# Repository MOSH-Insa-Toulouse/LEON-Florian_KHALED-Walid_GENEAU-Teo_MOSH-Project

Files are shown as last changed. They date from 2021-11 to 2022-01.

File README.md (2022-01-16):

___

# Keywords

___
> Arduino, Kicad, The Thing Networks, Lora, Node-Red, LT-spice  

___
# Membres du groupe

> Ce projet à été réalisé par : 
> - GENEAU Téo
> - KHALED Walid
> - LEON Florian
> 
___
# Description générale du projet 

Nous voulons dans ce projet réaliser un smart device, nous voulons récupérer les données d’un capteur de gaz et les envoyer via le protocole LORA sur le site TTN et ensuite afficher les données du capteur sur un Dashboard sur Node-Red. Nous nous intéressons aussi à la consommation d’Energie du capteur, donc nous allons utiliser le capteur sous un mode réveillé (très bref moment) pour mesurer et envoyer les données et un autre mode endormi où il ne consomme quasiment rien (pendant la majorité du temps).     

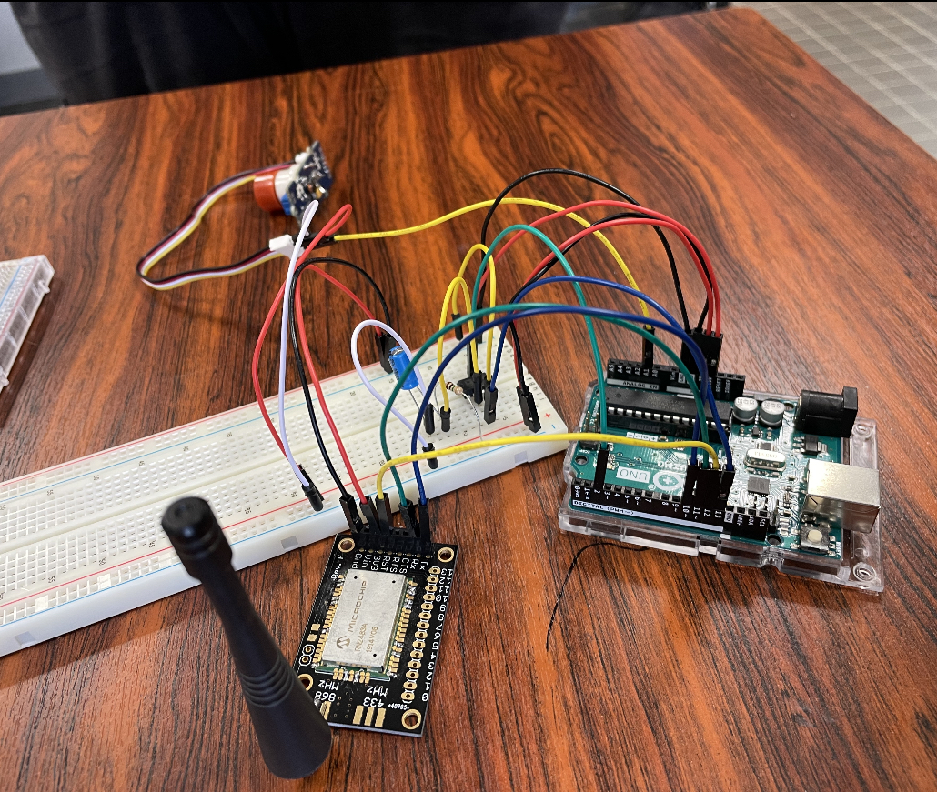
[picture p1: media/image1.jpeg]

___
# Partie 1 : Conception du PCB 

Le Shield contient un circuit d’adaptation d’impédance pour relier le capteur de gaz au microcontrôleur (Arduino Uno) ainsi qu’un circuit d’interruption qui gère les deux mode «Sleep» et «Wake-up» du circuit et du capteur de gaz.

Un connecteur est prévu pour relier le circuit à l’antenne LORA. 

L’emplacement réservé au capteur de gaz est au milieu du PCB en forme de petits cercles. 

### **Schéma Kicad**

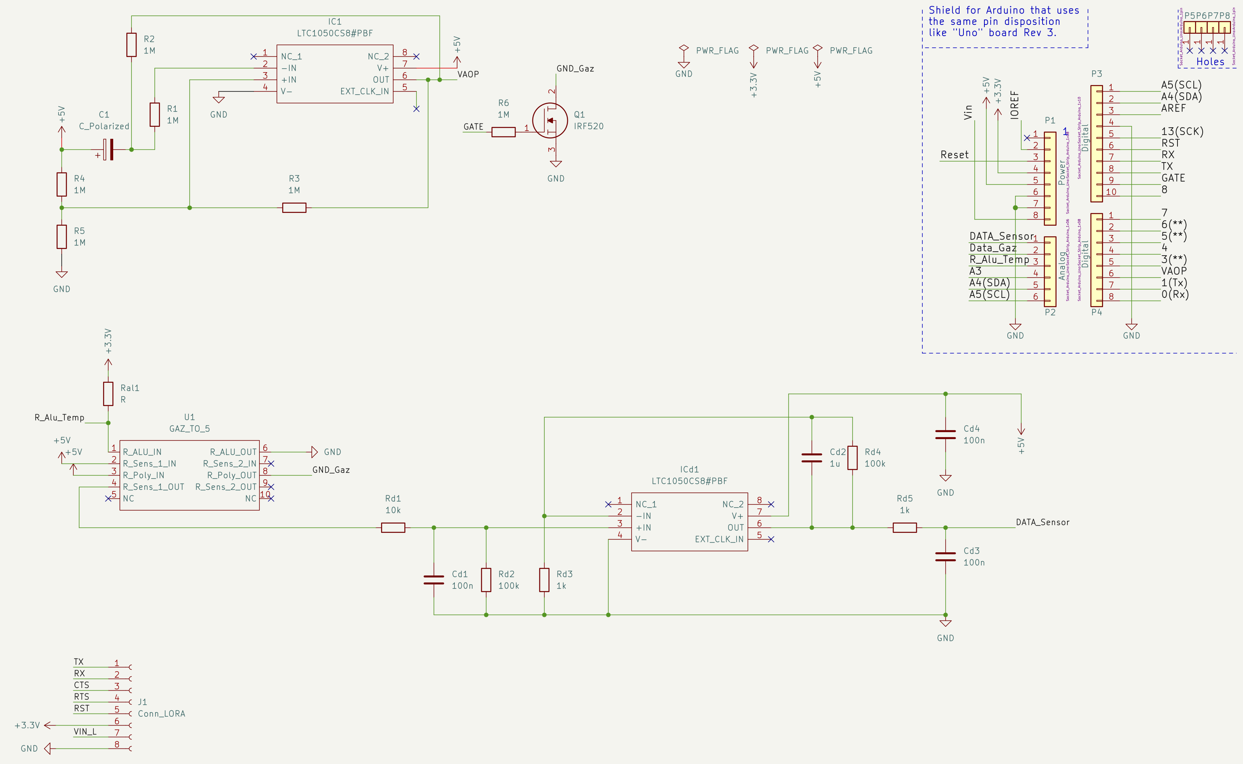
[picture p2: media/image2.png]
    

### **Visualisation du PCB** 

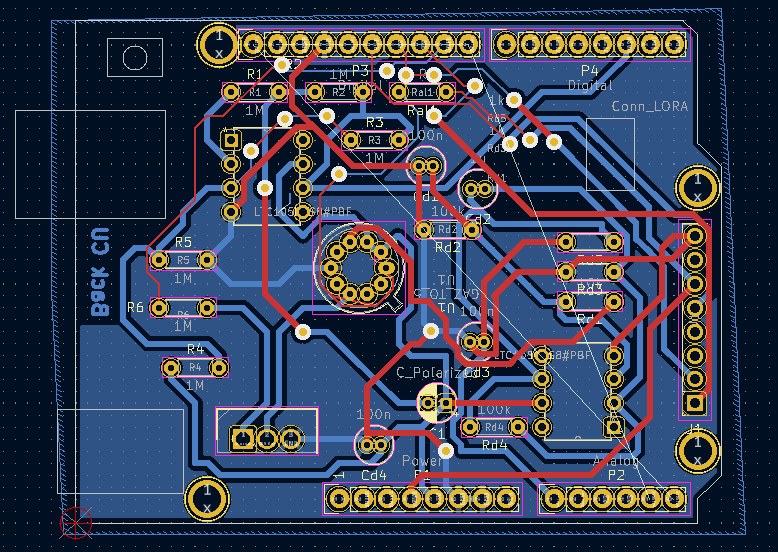
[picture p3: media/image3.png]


### **Visualisation du Shield en 3D** 

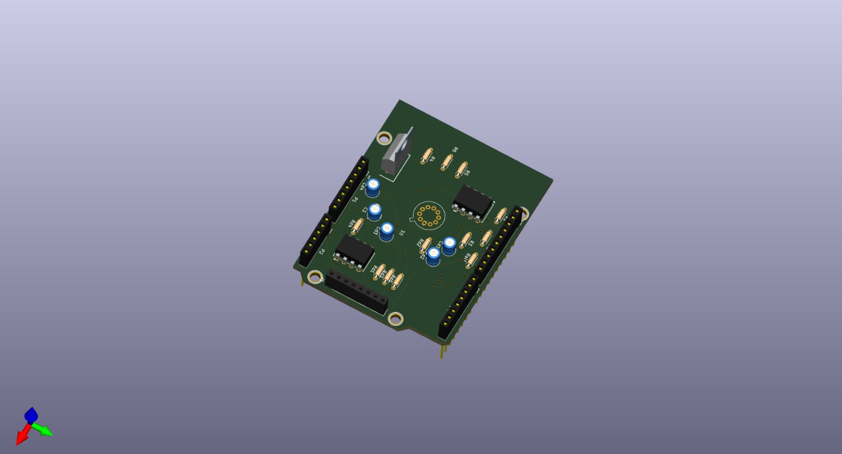
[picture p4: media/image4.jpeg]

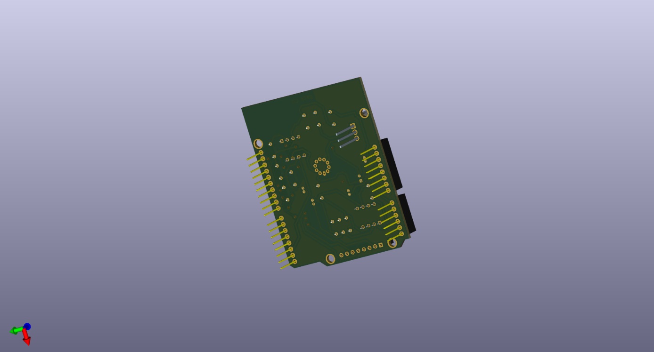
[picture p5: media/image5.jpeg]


___
# Partie LT-SPICE 

Afin de simuler notre circuit d’interruption et gérer la consommation d’Energie du circuit nous avons utilisé LT-SPICE afin de simuler le comportement que nous désirons. 

Nous remarquons sur les deux figures suivantes qu’en variant les paramètres des différents composants du circuit notamment les résistances, nous parvenons à contrôler la durée d’interruption. 

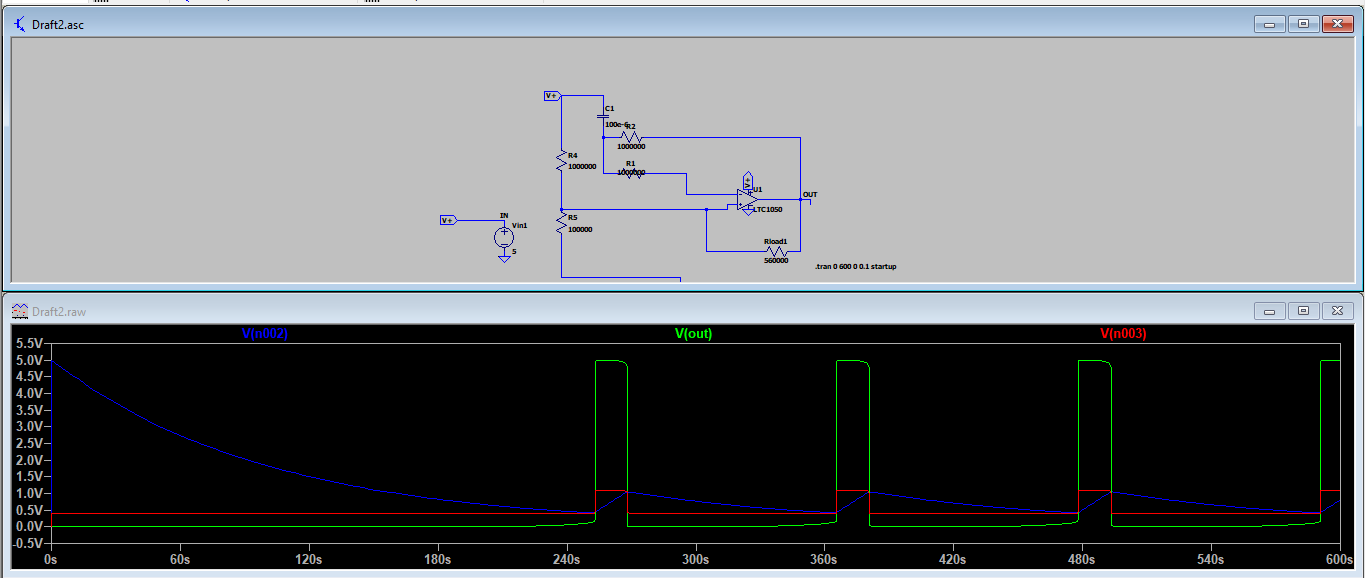
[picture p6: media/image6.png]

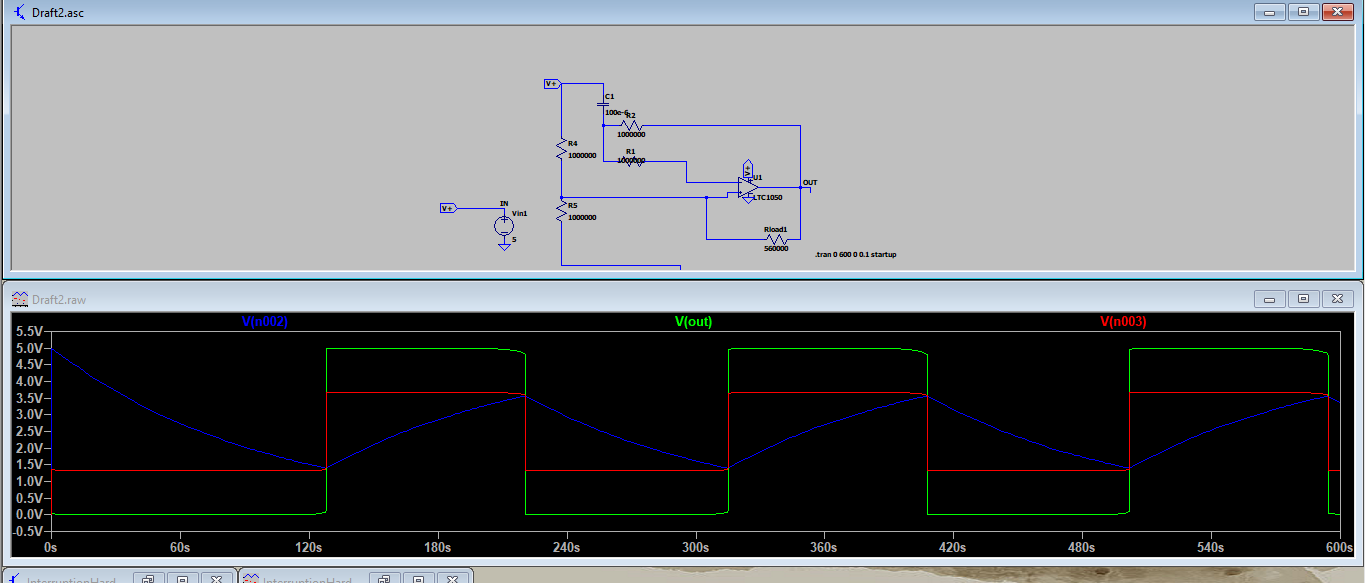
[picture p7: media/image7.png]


___
# Partie Arduino 

Nous utilisons l’Arduino UNO comme microcontrôleur accompagné d’une breadboard pour monter le circuit prototype (circuit d’interruption + capteur de gaz groove + Antenne LORA). 

> Le code Arduino est composé des parties suivantes : 
>
> - Une partie d’acquisition des données du capteur et affichage sur moniteur série  
> - Une partie de configuration de la connexion TTN – LORA 
> - Une partie de gestion des deux modes Sleep et Wake-Up 

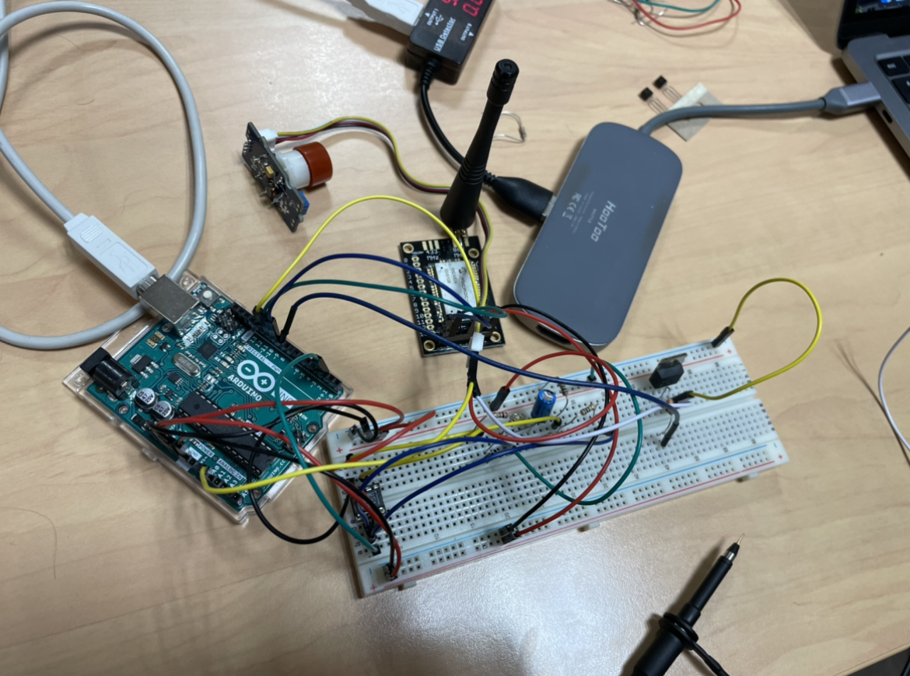
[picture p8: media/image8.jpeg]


### **Affichage des données sur TTN** 

Les données sont envoyées sur le site TTN via LORA. 

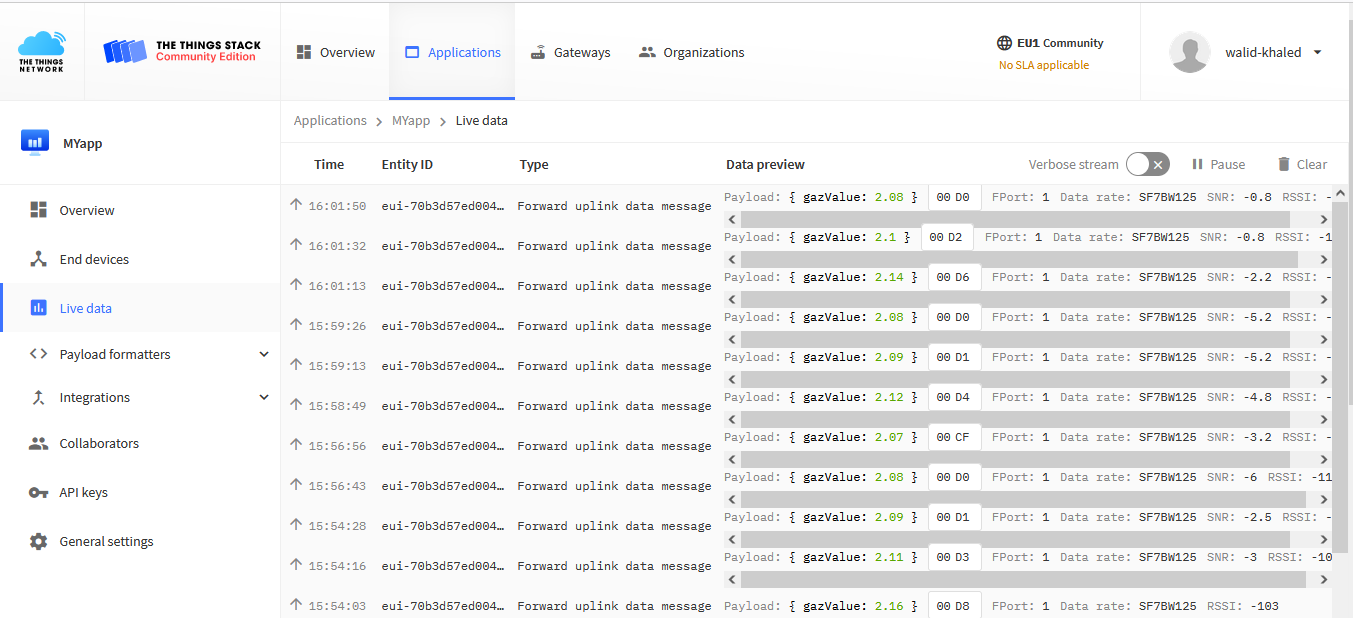
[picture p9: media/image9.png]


Le code suivant nous permet de décoder les valeurs en hexadécimal reçues : 
```javascript
function decodeUplink(input) {
var data = input.bytes[0] << 8  | input.bytes[1];
  return {
    data: {
      gazValue: data/100
    },
    warnings: [],
    errors: []
  };
}
```

### **Partie consommation Energie**

Dans le but de diminuer au maximum la consommation d’Energie de notre système, nous avons utilisé un circuit d’interruption, nous arrivons même à éteindre et à rallumer le capteur avec ce circuit en rajoutant un transistor ce qui réduit énormément la consommation d’Energie du circuit car c’est le capteur qui consomme la quasi-totalité de l’Energie consommée par tout le circuit.

Ainsi, nous avons mis en place deux types d’interruption pour optimiser la consommation de notre circuit : une interruption matérielle et logicielle.

Notre interruption matérielle consiste en un déclenchement cyclique externe.

Pour cela, nous avons utilisé un AOP pour faire un comparateur, le circuit permet de généré des ondes carrées bases fréquences et de créer un circuit oscillateur permettant de faire varier la tension entre 0 et 5V de manière cyclique. Il est possible de modifier la fréquence en modifiant les valeurs de la capacité ou bien des résistances. En effet, si on augmente par exemple la valeur de la capacité, la fréquence diminuera et inversement. 

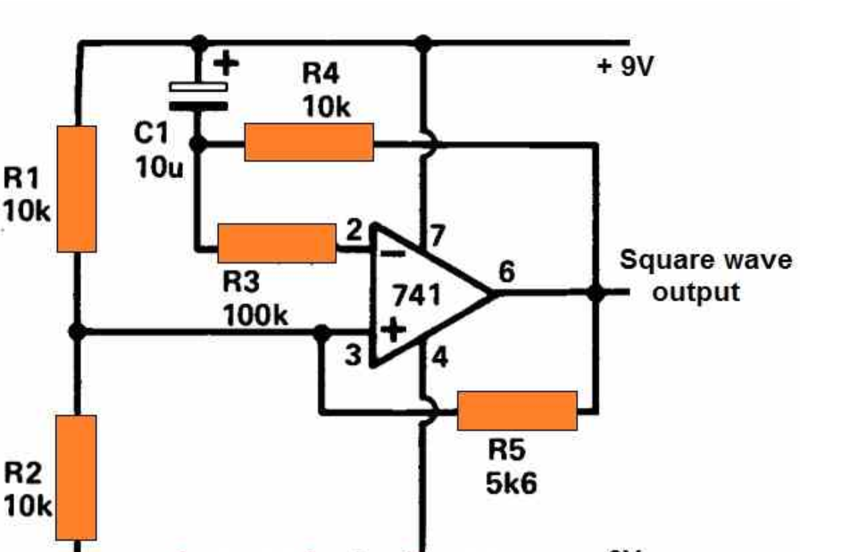
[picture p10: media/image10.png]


Nous avons simulé le circuit sur LT-Spice pour le choix des valeurs des résistances et de la capacité afin d’obtenir des périodes d’activités et d’inactivités adaptées à notre application.

L’interruption logicielle est réalisée par le code présent sur la carte. On réalise une interruption logicielle lorsque le circuit est dans une période inactive pour activer ou désactiver le capteur de gaz.

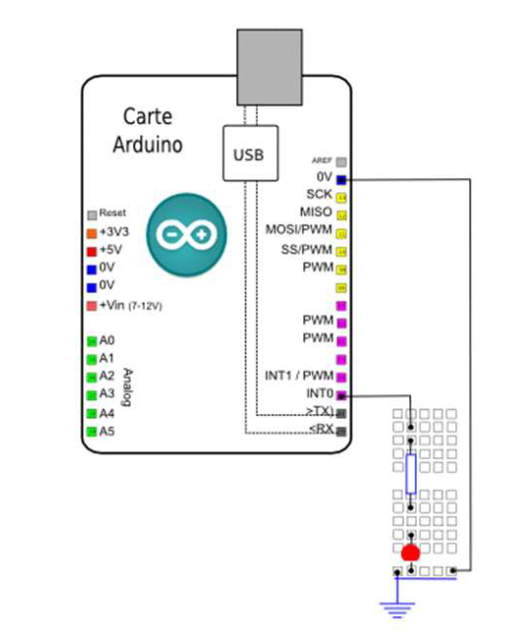
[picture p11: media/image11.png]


<ins>*Schéma du montage pour l’interruption logicielle (ici une LED à la place du capteur de gaz)*</ins>

Les figures suivantes montrent le comportement du système : 

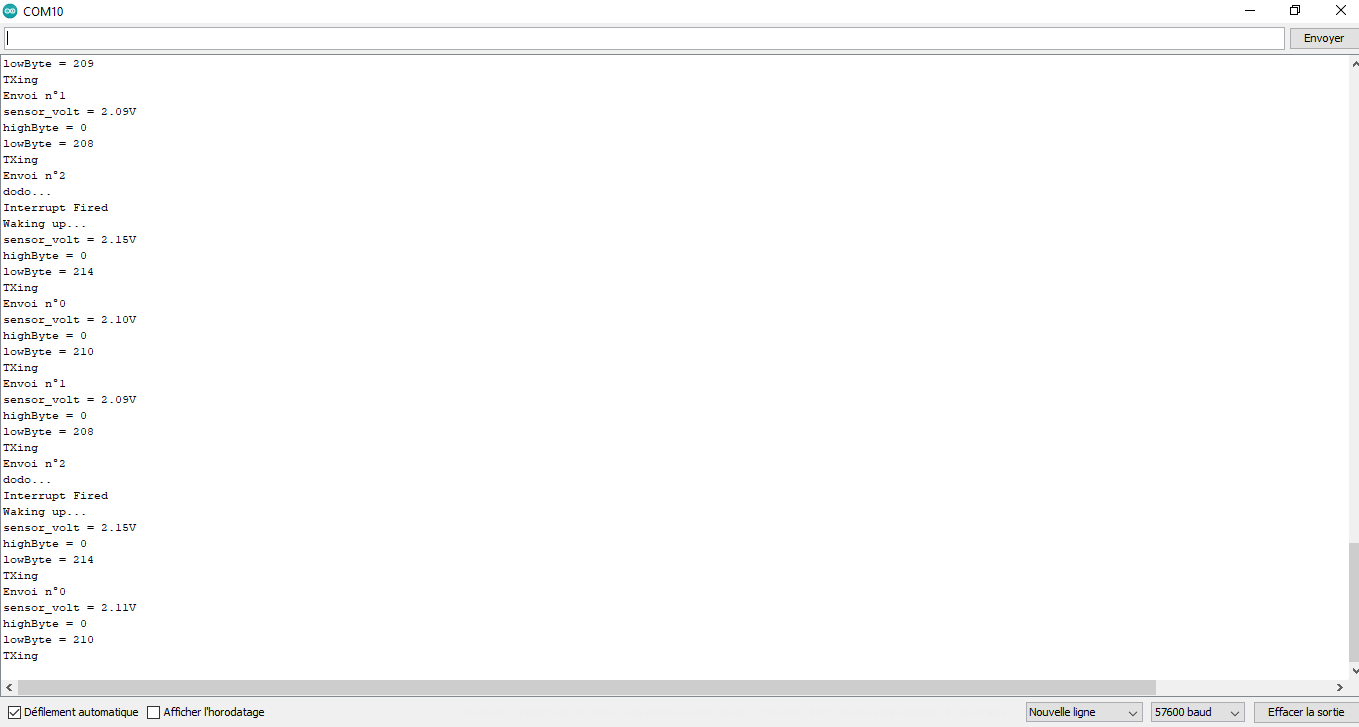
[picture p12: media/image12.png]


L’interruption est annulée et le capteur se réveil «Wake-Up» prend la mesure et l’envoie (3 envoies pour éviter une potentiel perte du message) et se remet en mode «Sleep» pour s’en dormir. 

> «Dodo» (le capteur retourne au mode Sleep)
> 0 V en sortie de l’AOP 



> Mode Wake-Up et envoie de 3 messages (données)  
> 5 V en sortie de l’AOP

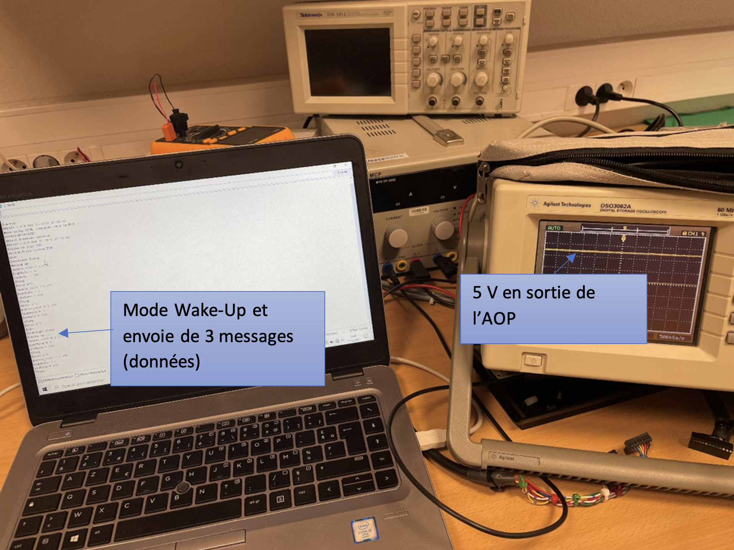
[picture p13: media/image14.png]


### **Bilan de puissance consommée**
Nous avons mesuré le courant en sortie du circuit, pour cela nous avons utilisé un détecteur d’intensité USB

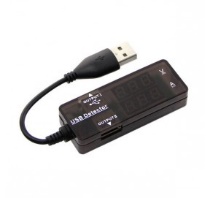
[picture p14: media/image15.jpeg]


<p style="text-align:center;"><ins><em>Détecteur de tension/intensité USB</em></ins></p>

Il permet de réaliser des mesures de courant consommé sur un port USB et ce en temps réel. Nous avons alors pu établir un tableau de mesures.

> Pour cela, nous avons mesurer la consommation en courant du circuit en fonction de son comportement :
> - En mode wake-up (actif), lorsque le circuit d’oscillation impose une tension à 5V.
> - En mode sleep, lorsque le circuit d’oscillation impose une tension à 0V et que le capteur de gaz est activé.
> - En mode sleep, lorsque le circuit d’oscillation impose une tension à 0V et que le capteur de gaz est désactivé par interruption logicielle.

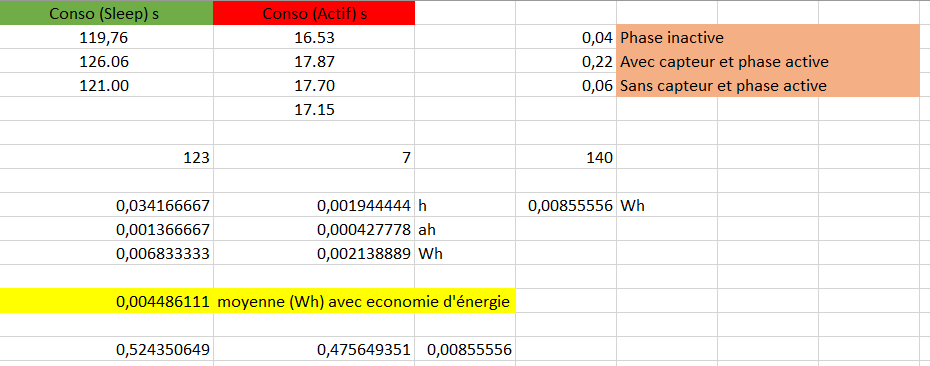
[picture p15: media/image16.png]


Nous pouvons observer que c’est l’interruption matérielle qui a le plus d’impact sur la consommation, en effet, on passe de **0.22 à 0.04** A lors des périodes de sleep imposées par l’AOP comparateur, soit une réduction de **0.18 A**. Tandis que, l’interruption logicielle, elle, permet une économie de **0.16 A** en passant de **0.22 A à 0.06 A**, cette interruption permet de ne plus alimenter le capteur lors de la phase active, on peut alors remarquer que c’est le capteur de gaz qui consomme le plus dans le circuit avec une consommation correspond au **0.16 A** de différence. 

De plus, on a mesuré la durée des périodes de sleep et de wake-up du circuit, on observe une période moyenne de **123 secondes** pour les périodes inactives du circuit contre 17 secondes en moyenne pour la phase active, or, l’interruption logicielle active le capteur que pour une durée de **7 secondes**.

On convertit en heure et on multiplie par les valeurs de courant correspondantes mesurées pour obtenir la mesure en Ah, puis on multiplie par le voltage (5V) pour obtenir une mesure de puissance en Wh.

On a bien :
<!-- $$
P_{sleep} = \frac{123}{3600} \cdot 0.04 \cdot 5 = 6.833 \enspace mWh
$$ --> 



contre

<!-- $$
P_{actif} = \frac{7}{3600} \cdot 0.22 \cdot 5 = 2.138 \enspace mWh
$$ --> 



Soit P<sub>moy</sub> la puissance moyenne de notre système avec ce mécanisme sleep/wake-up.
<!-- $$
P_{moy} = \frac{P_{sleep} + P_{actif}}{2} = 4.4861 \enspace mWh
$$ --> 



Or, sans ce mécanisme on a bien une consommation de 0.22 A et 5 V pendant 140 s (123 + 17) soit :

<!-- $$
ConsoAmpere = \frac{140}{3600} \cdot 0.22 = 0.0085 \enspace Ah
$$ --> 



et 

<!-- $$
P_{max} = ConsoAmpere \cdot 5 = 42.77 \enspace mA
$$ --> 



On observe qu’on a quasiment divisé par 10 la consommation classique avec la mise en place de nos interruptions logicielles et matérielles.

<!-- $$
5V \cdot ah = Wh 
$$ --> 



---
# Partie Node-Red 
---
Afin d’afficher les données de notre capteur, Nous utilisons Node-Red, cela se fait en établissant une connexion via le protocole MQTT entre Node-Red et le site TTN. 

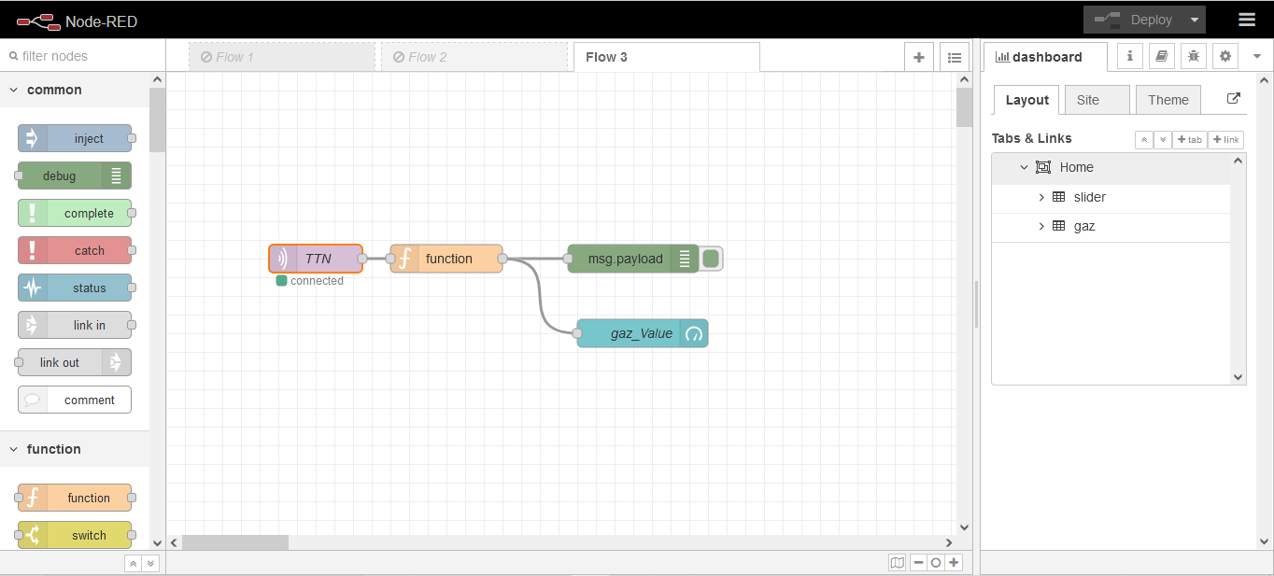
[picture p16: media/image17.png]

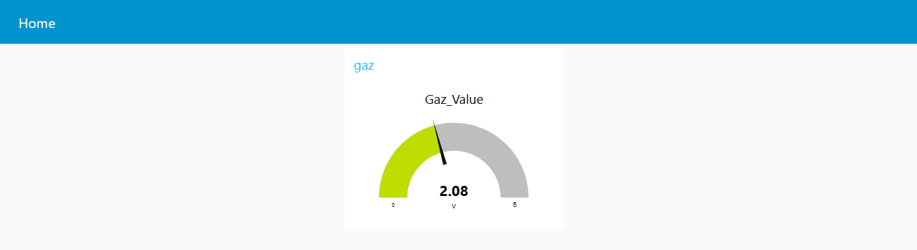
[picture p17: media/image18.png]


### **Paramétrage du nœud MQTT :** 

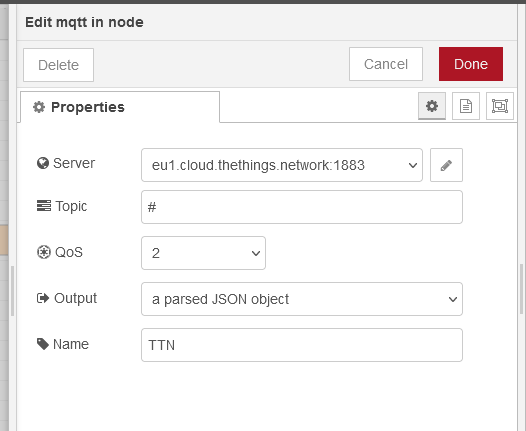
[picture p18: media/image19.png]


Des améliorations peuvent être faites comme par exemple afficher l’historique des valeurs de gaz pendant la journée ou bien pendant le mois…

Rajouter des boutons ou des sliders pour agir sur des actionneurs en down-link pour avertir par exemple via une alarme d’une valeur de gaz trop importante… 

___
___

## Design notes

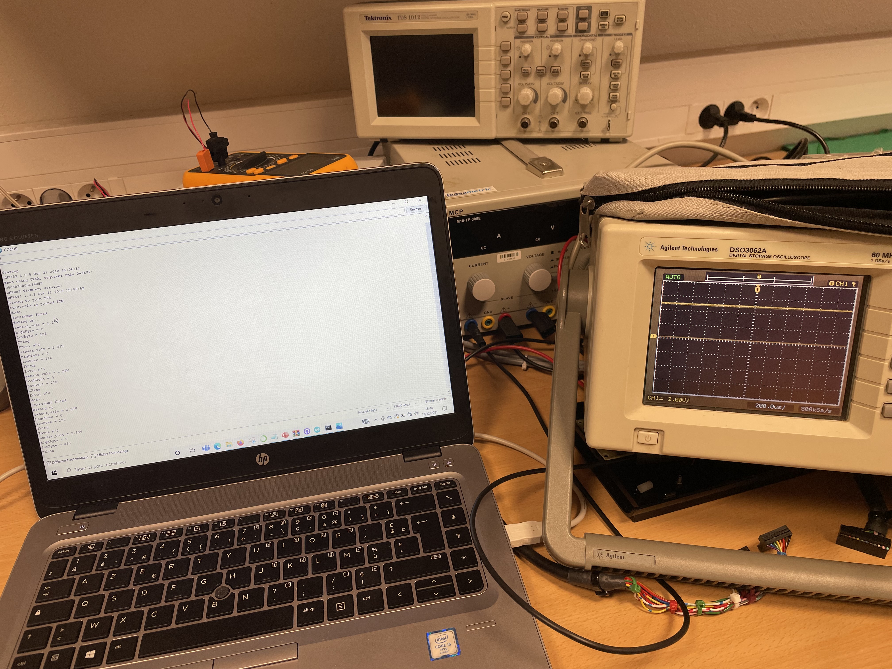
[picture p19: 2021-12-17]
Photos/wake_up.jpg

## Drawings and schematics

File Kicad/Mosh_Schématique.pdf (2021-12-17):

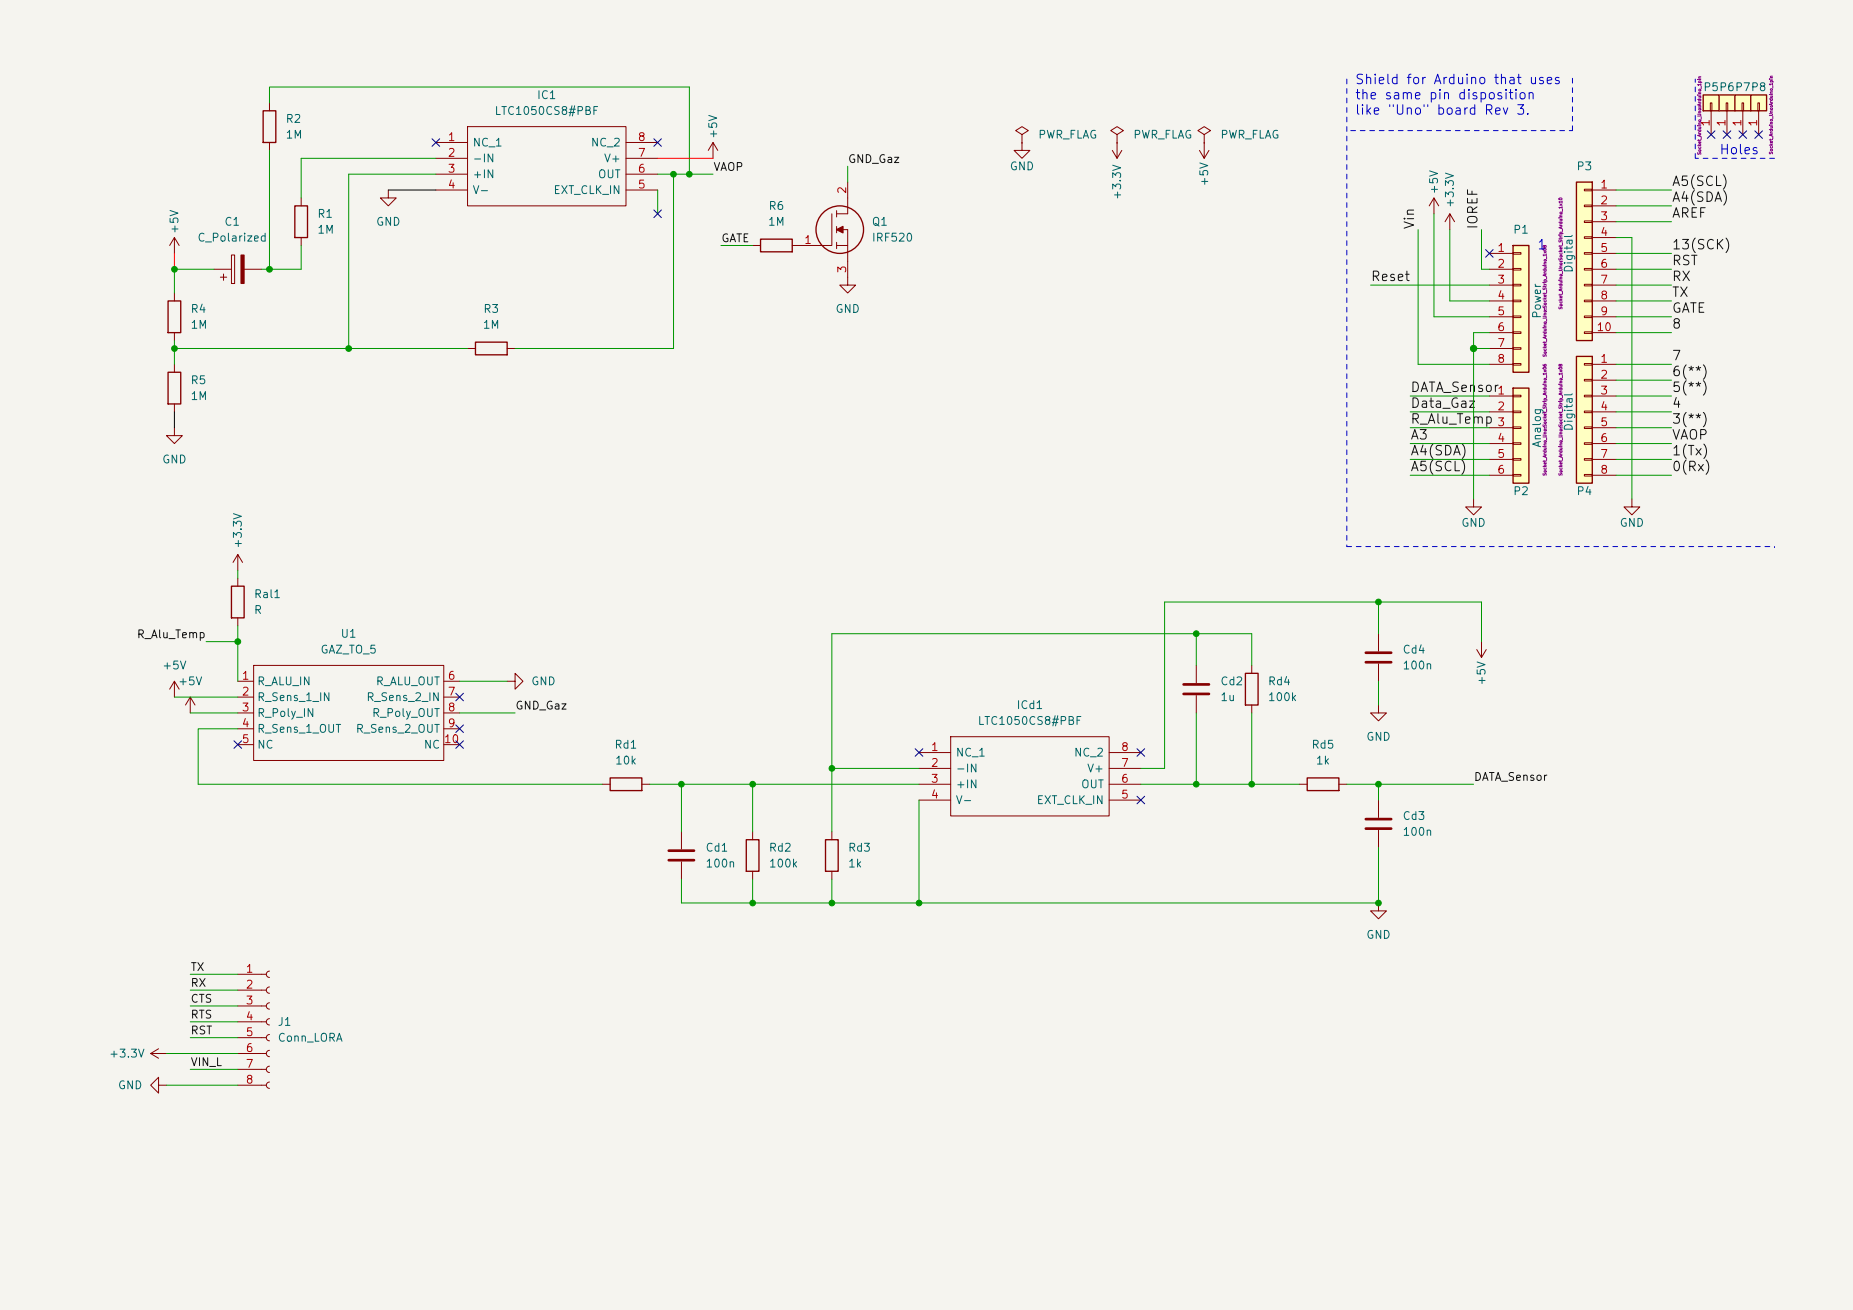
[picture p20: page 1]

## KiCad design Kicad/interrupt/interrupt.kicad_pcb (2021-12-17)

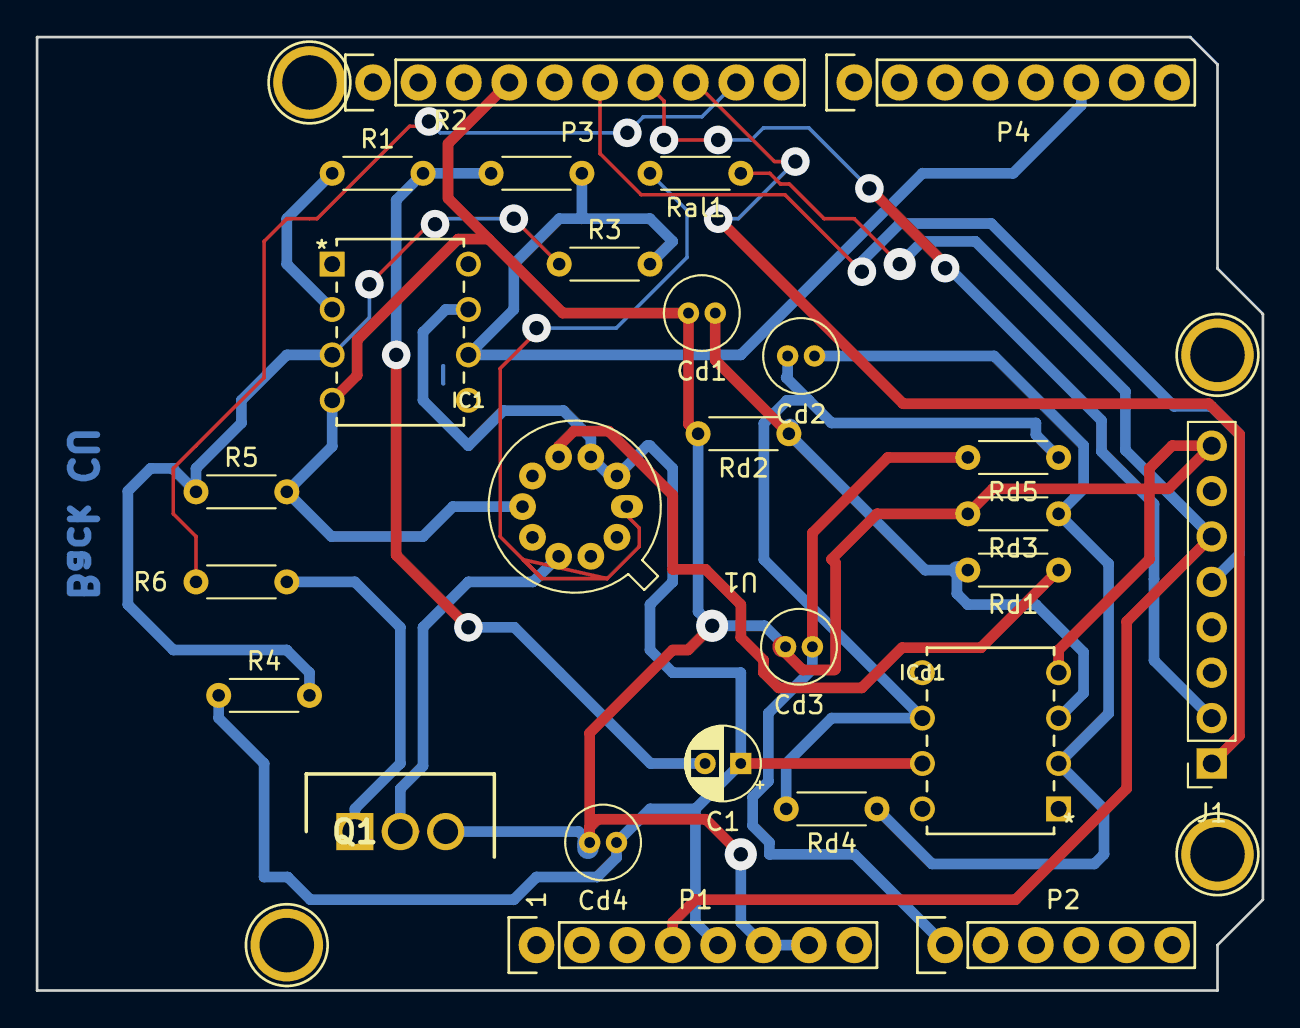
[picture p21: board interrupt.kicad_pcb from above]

Board: 2 copper layers, 68.6 x 53.3 mm, 30 parts (0 on the bottom side), 21 nets.

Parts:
C1: C_Polarized; CP_Radial_D4.0mm_P2.00mm
Cd1, Cd3, Cd4: 100n; C_Radial_D4.0mm_H5.0mm_P1.50mm
Cd2: 1u; C_Radial_D4.0mm_H5.0mm_P1.50mm
IC1: LTC1050CS8#PBF; PDIP-8_N
ICd1: LTC1050CS8#PBF; PDIP-8_N
J1: Conn_LORA; PinSocket_1x08_P2.54mm_Vertical
P1: Power; Socket_Strip_Arduino_1x08
P2: Analog; Socket_Strip_Arduino_1x06
P3: Digital; Socket_Strip_Arduino_1x10
P4: Digital; Socket_Strip_Arduino_1x08
P5, P6, P7, P8: CONN_01X01; Arduino_1pin
Q1: IRF520; TO254P465X1024X2050-3P
R1, R2, R3, R4, R5, R6: 1M; R_Axial_DIN0204_L3.6mm_D1.6mm_P5.08mm_Horizontal
Ral1: R; R_Axial_DIN0204_L3.6mm_D1.6mm_P5.08mm_Horizontal
Rd1: 10k; R_Axial_DIN0204_L3.6mm_D1.6mm_P5.08mm_Horizontal
Rd2, Rd4: 100k; R_Axial_DIN0204_L3.6mm_D1.6mm_P5.08mm_Horizontal
Rd3, Rd5: 1k; R_Axial_DIN0204_L3.6mm_D1.6mm_P5.08mm_Horizontal
U1: GAZ_TO_5; GAZ_TO-5

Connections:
+3V3: J1.6, P1.4, Ral1.1
+5V: C1.1, Cd4.1, IC1.7 (V+), ICd1.7 (V+), P1.5, R4.1, U1.2 (R_Sens_1_IN), U1.3 (R_Poly_IN)
/A4(SDA): P2.5, P3.2
/A5(SCL): P2.6, P3.1
/DATA_Sensor: Cd3.1, P2.1, Rd5.2
/GATE: P3.9, R6.1
/GND_Gaz: Q1.2, U1.8 (R_Poly_OUT)
/RST: J1.5, P3.6
/RX: J1.2, P3.7
/TX: J1.1, P3.8
/VAOP: IC1.6 (OUT), P4.6, R2.1, R3.2
GND: Cd1.2, Cd3.2, Cd4.2, IC1.4 (V-), ICd1.4 (V-), J1.8, P1.6, P1.7, P3.4, Q1.3, R5.2, Rd2.2, Rd3.2, U1.6 (R_ALU_OUT)
unnamed: C1.2, R1.2, R2.2
unnamed: Cd1.1, ICd1.3 (+IN), Rd1.2, Rd2.1
unnamed: Cd2.1, ICd1.2 (-IN), Rd3.1, Rd4.1
unnamed: Cd2.2, ICd1.6 (OUT), Rd4.2, Rd5.1
unnamed: IC1.2 (-IN), R1.1
unnamed: IC1.3 (+IN), R3.1, R4.2, R5.1
unnamed: Q1.1, R6.2
unnamed: Ral1.2, U1.1 (R_ALU_IN)
unnamed: Rd1.1, U1.4 (R_Sens_1_OUT)

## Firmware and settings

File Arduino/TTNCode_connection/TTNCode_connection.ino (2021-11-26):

/*
 * Author: JP Meijers
 * Date: 2016-02-07
 * Previous filename: TTN-Mapper-TTNEnschede-V1
 *
 * This program is meant to be used with an Arduino UNO or NANO, conencted to an RNxx3 radio module.
 * It will most likely also work on other compatible Arduino or Arduino compatible boards, like The Things Uno, but might need some slight modifications.
 *
 * Transmit a one byte packet via TTN. This happens as fast as possible, while still keeping to
 * the 1% duty cycle rules enforced by the RN2483's built in LoRaWAN stack. Even though this is
 * allowed by the radio regulations of the 868MHz band, the fair use policy of TTN may prohibit this.
 *
 * CHECK THE RULES BEFORE USING THIS PROGRAM!
 *
 * CHANGE ADDRESS!
 * Change the device address, network (session) key, and app (session) key to the values
 * that are registered via the TTN dashboard.
 * The appropriate line is "myLora.initABP(XXX);" or "myLora.initOTAA(XXX);"
 * When using ABP, it is advised to enable "relax frame count".
 *
 * Connect the RN2xx3 as follows:
 * RN2xx3 -- Arduino
 * Uart TX -- 10
 * Uart RX -- 11
 * Reset -- 12
 * Vcc -- 3.3V
 * Gnd -- Gnd
 *
 * If you use an Arduino with a free hardware serial port, you can replace
 * the line "rn2xx3 myLora(mySerial);"
 * with     "rn2xx3 myLora(SerialX);"
 * where the parameter is the serial port the RN2xx3 is connected to.
 * Remember that the serial port should be initialised before calling initTTN().
 * For best performance the serial port should be set to 57600 baud, which is impossible with a software serial port.
 * If you use 57600 baud, you can remove the line "myLora.autobaud();".
 *
 */
#include <rn2xx3.h>
#include <SoftwareSerial.h>
#include <avr/sleep.h>

#define interruptPin 2
#define transistorPin 9

SoftwareSerial mySerial(10, 11); // RX, TX

//create an instance of the rn2xx3 library,
//giving the software serial as port to use
rn2xx3 myLora(mySerial);

// the setup routine runs once when you press reset:
void setup()
{
  pinMode(interruptPin, INPUT);
  //output LED pin
  pinMode(13, OUTPUT);
  pinMode(transistorPin, OUTPUT);
  led_on();

  // Open serial communications and wait for port to open:
  Serial.begin(57600); //serial port to computer
  mySerial.begin(9600); //serial port to radio
  Serial.println("Startup");

  initialize_radio();

  //transmit a startup message
  myLora.tx("TTN Mapper on TTN Enschede node");

  led_off();
  delay(2000);
}


void initialize_radio()
{
  //reset rn2483
  pinMode(12, OUTPUT);
  digitalWrite(12, LOW);
  delay(500);
  digitalWrite(12, HIGH);


  delay(100); //wait for the RN2xx3's startup message
  mySerial.flush();
  //Autobaud the rn2483 module to 9600. The default would otherwise be 57600.
  myLora.autobaud();
  String t = myLora.sendRawCommand("sys get ver");
  Serial.println(t);

  //check communication with radio
  String hweui = myLora.hweui();
  while(hweui.length() != 16)
  {
    Serial.println("Communication with RN2xx3 unsuccessful. Power cycle the board.");
    Serial.println(hweui);
    delay(10000);
    hweui = myLora.hweui();
  }

  //print out the HWEUI so that we can register it via ttnctl
  Serial.println("When using OTAA, register this DevEUI: ");
  Serial.println(myLora.hweui());
  Serial.println("RN2xx3 firmware version:");
  Serial.println(myLora.sysver());

  //configure your keys and join the network
  Serial.println("Trying to join TTN");
  bool join_result = false;


  /*
   * ABP: initABP(String addr, String AppSKey, String NwkSKey);
   * Paste the example code from the TTN console here:
   */
  const char *devAddr = "260B1AE1";
  const char *nwkSKey = "D8D8447FDD24234D1F6699C7B0AB9374";
  const char *appSKey = "684FB7E113DC0D328C0D04F8BF814B31";

  join_result = myLora.initABP(devAddr, appSKey, nwkSKey);

  /*
   * OTAA: initOTAA(String AppEUI, String AppKey);
   * If you are using OTAA, paste the example code from the TTN console here:
   */
  //const char *appEui = "260B1AE1";
  //const char *appKey = "3D1351C97C367C1E063B5D99C24C266E";
  //join_result = myLora.initOTAA(appEui, appKey);


  while(!join_result)
  {
    Serial.println("Unable to join. Are your keys correct, and do you have TTN coverage?");
    delay(60000); //delay a minute before retry
    join_result = myLora.init();
  }
  Serial.println("Successfully joined TTN");

}

void read_data() {
    float sensor_volt;
    float sensorValue;
   
    sensorValue = analogRead(A0);
    sensor_volt = sensorValue/1024*5.0;
    //sensor_volt *= 100;
    Serial.print("sensor_volt = ");
    Serial.print(sensor_volt);
    Serial.println("V");

    uint32_t data = sensor_volt*100;
    byte payload[2];
    payload[0] = highByte(data);
    Serial.print("highByte = ");
    Serial.println(payload[0]);
    payload[1] = lowByte(data);
    Serial.print("lowByte = ");
    Serial.println(payload[1]);
    Serial.println("TXing");

    myLora.txBytes(payload, sizeof(payload)); //one byte, blocking function

    led_off();
}

void goingToSleep() {
  sleep_enable();
  Serial.println("dodo...");
  delay(100);
  attachInterrupt(0, wakeUp, RISING);
  set_sleep_mode(SLEEP_MODE_PWR_DOWN);
  //delay(500);
  sleep_mode();
  Serial.println("Waking up...");
  
}

void wakeUp() {
  Serial.println("Interrupt Fired");
  sleep_disable();
  detachInterrupt(0);
}
// the loop routine runs over and over again forever:
void loop()
{
    
    goingToSleep();
    digitalWrite(transistorPin, HIGH);
    delay(10000);
    for (int i = 0; i < 3; i++) {
      read_data();
      Serial.print("Envoi n°");
      Serial.println(i);
      delay(200);
    }
    digitalWrite(transistorPin, LOW);
}

void led_on()
{
  digitalWrite(13, 1);
}

void led_off()
{
  digitalWrite(13, 0);
}

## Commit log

2021-11-18 Depot initial + code arduino TTN + node-red
2021-11-26 Rajout bilan puissance
    [bilan_puissance.xlsx]
2021-11-26 simulation spice
    captures des simulations circuit d'interruptions
2021-11-26 fichier_kicad_circuit_interruption
    le fichier représente un shield qui se fixera sur arduino il aura deux emplacements pour fixer lora et capteur gaz ainsi que le circuit sleep
    [interrupt.kicad_pcb, interrupt.kicad_sch]
2021-11-30 TP_elec_analog
    fichiers de simulation circuit filtrage gaz sensor avec les résultats
2021-12-03 MODIF schéma
    [interrupt.kicad_pcb, interrupt.kicad_sch]
2021-12-06 modification schéma kicad
    [interrupt.kicad_sch]
2022-01-26 Added gaz sensor Datasheet
